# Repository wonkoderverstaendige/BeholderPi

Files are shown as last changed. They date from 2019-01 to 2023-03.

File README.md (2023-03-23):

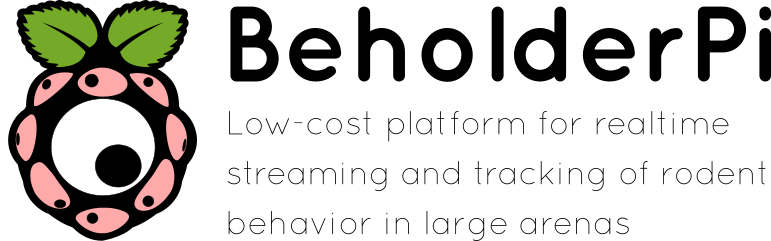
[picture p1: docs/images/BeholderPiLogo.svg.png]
BeholderPi logo BeholderPI logo


# Outline

- scalable array of networked camera nodes
- low-cost (relatively) ~100--200 Euro/node
- 800x600 @ 30 fps in visible or IR
- low latency preview of merged views
- synchronized to sub-millisecond time resolution
- hardware accelerated encoding
- synchronization with external systems (e.g. elecrophysiology recordings)

# Hardware

- [RaspberryPi 3B+/4B](https://www.raspberrypi.org/documentation/hardware/raspberrypi/README.md)
- [Raspberry/Picamera compatible camera module](https://www.raspberrypi.org/documentation/hardware/camera/README.md)
    - e.g. Camera Module v2 (8MP, FOV: 62.2° horizontal, 48.8° vertical)
    - **Read:** [How the PiCamera works](https://picamera.readthedocs.io/en/release-1.13/fov.html)
- [PoE hat](https://www.raspberrypi.org/products/poe-hat/) for power/network
- A decent receiving computer (ideally 1 CPU core/node)
- optional hardware encoding GPU
- PoE capable ethernet switch if PoE is used

# Software
- based on Picamera, ZMQ, OpenCV, FFmpeg

# Inspiration
## Raspicam paper
Inspiration of the system was taken from prior work done by [Saxena et al. 2018](https://www.physiology.org/doi/full/10.1152/jn.00215.2018),
[code here](https://github.com/DeshmukhLab/PicameraPaper).

# Installation
1) [System Overview](docs/SystemOverview.md)
2) [Beholder Installation](docs/Installation_Beholder.md)
3) [Eye Installation](docs/Installation_Eye.md)
4) [General Usage](docs/Usage.md)
5) [Troubleshooting](docs/Troubleshooting.md)

## Hardware
- [Camera Mounts](docs/CameraMounts.md)
- [Sync Lights](docs/SyncLights.md)

## Processing
- [Stitching](docs/processing/Stitching.md)
- [Synchronization](docs/Synchronization.md)
- [Tracing](docs/Tracing.md)
- [Tracking](docs/Tracking.md)

# TODO
- see [current todo list](docs/todo.md)

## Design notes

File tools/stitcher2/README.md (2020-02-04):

# Stitching Videos
Create a new directory named with the timestamp of the videos and copy the original copies into it.

## Calculate alignment matrix
For each camera angle we need to pre-calculate the transformation matrix with the GUI tool. Start the GUI with
    
    `python align_gui.py --target [target image path] [source image path]`

where the target image is a ground-truth image of a flat top-down view on the maze
For example:

    `python align_gui.py --target "D:\data\targets\mouse_hexmaze.png" "D:\data\2018-10-02_04-40-59_cam_0.avi"`
    
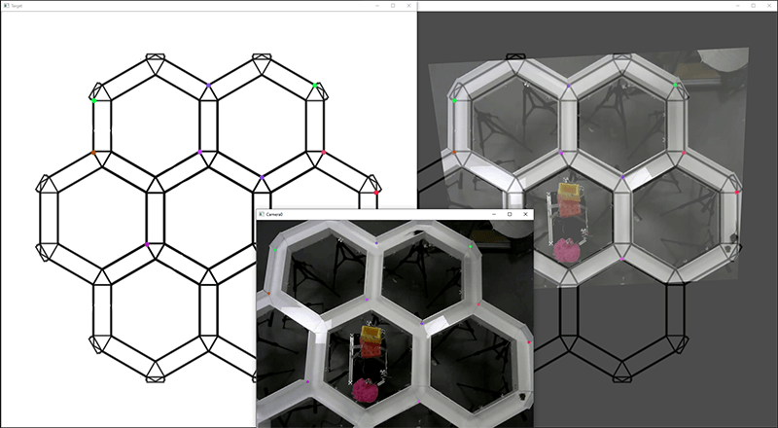
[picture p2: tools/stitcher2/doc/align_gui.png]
Align GUI

   
The GUI should open three windows. One is the target image, one the source camera view, and one a preview. Double click
on a point in the target view, a colored dot appears marking the location. Double click on the corresponding location
in the source view. A dot with the same color should appear there, too. The dots should all represent locations in a
single plane, for example the floor of the maze. This is important!

Once three such points where added, the preview should update and show you the current estimate, but will only align
well when at least four point pairs were added. When you are happy with the alignment, press `s` on the keyboard to
save, and `q` to quit. The transformation (homography) matrix, label and preview images are stored alongside the 
original files. Check they are ok.

Repeat for all cameras/videos.

## Stitch images
With the precalculted transformation matrix the images can now be perspective corrected and merged.

`python stitch.py --target [target path] [sources]`

Sources should be paths all camera views. To make it easier, if they all have the same name and just different camera 
number as is usually the case, the source can be specified with a wildcard, either `?` or  `*`. For example:

`python stitch.py --target "targets\mouse_hexmaze.png" "D:\data\2018-10-02_04-40-59_cam_*.avi"`

Additional parameters of note are `--preview`, giving you a preview of what happens. This is great to tune in on a final
look, but slows processing down. `--cropx` and `--cropy` allow to trim the borders of the image. `--delays` allows to 
either start the video in the middle instead of the start, but also to compensate for temporal lag between the cameras.
If `--skip` is used it must be specified for each source. E.g. for a two camera set of videos `--skip 0 0`.
Together with `--num_frames` to limit the number of frames to be extracted, segments in the middle of a session can be
extracted.

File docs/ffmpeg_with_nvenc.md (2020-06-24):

```sh
sudo add-apt-repository ppa:graphics-drivers/ppa
sudo apt-get update && sudo apt-get -y upgrade
sudo apt-get install nvidia-kernel-source-418 nvidia-driver-418
```

This will cause freezes of the ubuntu desktop due to a conflict between the nvidia
drivers and the HWE stack. We need to reinstall the non-HWE Xorg packages.

`sudo apt install ubuntu-desktop` should pull all the non-Xorg packages in.

Next we need to grab the nvidia headers:

```sh
git clone https://git.videolan.org/git/ffmpeg/nv-codec-headers.git
cd nv-codec-headers
make
sudo make install
```

## The snap way (BAD)
Then we can just install the latest ffmpeg snap (e.g. 4.1 seems to work) with
`-nvenc-enabled` flag.

`sudo snap install ffmpeg`

--> HOWEVER, the snap has atrocious startup times, many times longer, especially the first launch. This can cause issues with dropped frames.

## The non-snap way (GOOD)
Instead we want to compile our own ffmpeg with NVENC support. Luckily I did this without taking notes due to time pressure in the moment... so you are on your own.

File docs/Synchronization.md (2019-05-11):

# NTP synchronization
## Chrony
Chrony acts as both NTP client as well as NTP server. We want to quickly synchronize on startup and then keep all
devices closely locked to within ~1 ms.

- Beholder acts as NTP server (with the `allow` directive).
- Spectator as secondary server to keep all log files and events synchronized?

## Current state (11-May-2019)
- chrony on Beholder keeps halting. Perhaps networking issue to sources on startup?

## Logging
- track logging information on the eyes to see actual offsets and throw into influxdb?

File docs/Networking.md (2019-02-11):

# Setup

When setting up, we need access to the internet (to pull packages etc.).
After that we can switch to the local beholder.pi network.

When connecting a freshly flashed raspberry, it will start broadcasting
discovery packages.

The `spectator` raspberry is running the local DHCP and DNS servers on
10.0.0.1 and has a static IP reserved for the beholder (currently antigoon)
at 10.0.0.11.

 >TODO: Install NTP server, too.

# Bootstrapping

- monitor the appearance of a new host in the discovery table.
- look up MAC adress of the new host:
    `ssh pi@host.ip 'cat /sys/class/net/eth0/address'`
- enter new MAC mapping in the `ansible/setup/network/vars.yml` file
- enter temporary IP in `ansible/setup/network/inventory`
- Execute the network setup playbook in the `ansible/setup/network` directory:
    `ansbible-playbook -i inventory main.yml`

This should set up the new host with proper IP.

- Verify new IP and correct host name in the discovery table
- update eye IP in `ansible/setup/network/inventory` file

> TODO: allow passing a new_host_ip variable to target only new hosts

<!--# Maintenance-->

<!--- For each node, start up wifi, connect to access point-->
<!--- update-->
<!--- shut down wifi-->

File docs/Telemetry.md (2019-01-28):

# InfluxDB telemetry

- install Raspbian Stretch Lite
- update && upgrade, set up ssh, keyboard, passwd, vim, byobu, htop etc...
- Set up InfluxDB repo
	- `$ curl -sL https://repos.influxdata.com/influxdb.key | sudo apt-key add -`
	- `$ echo "deb https://repos.influxdata.com/debian stretch stable" | sudo tee /etc/apt/sources.list.d/influxdb.list`
	- `$ sudo apt update`
	- `$ sudo apt install telegraf`, install also `influxdb kapacitor` on main pi

## InfluxDB
- `$ sudo systemctl start influxdb`, defaults to port 8086
- `$ influx` to start influxdb shell, `> auth` to authenticate

Influxdb will require authentication the moment here is a admin user.

- `> CREATE USER admin WITH PASSWORD 'adminpw' WITH ALL PRIVILEGES`
- in `/etc/influxdb/influxdb.conf` under `[http]` set `auth-enabled = true`

- `> CREATE DATABASE telegraf`
	- `> SHOW DATABASES`
    - `> CREATE USER telegraf WITH PASSWORD 'userpw'`
    	- (`> SET PASSWORD FOR "user" = 'abcdef'`  to change)
    - `> GRANT ALL ON telegraf TO telegraf`
    - `> SHOW USERS`
    
    Optionally set the retention policy to reduce space use
    - `> CREATE RETENTION POLICY thirty_days ON telegraf DURATION 30d REPLICATION 1 DEFAULT`
    - `> SHOW RETENTION POLICIES ON telegraf`

## Telegraf

To store the configuration file in the github repo, we need to either
modify the telegraf service, or link the default location to our version.

- create symlink from `/etc/telegraf/telegraf.conf` to repo conf file
- Add password and username environment variables to `/etc/default/telegraf`
- Add telegraf user to video group: `sudo usermod -G video telegraf` to access the videocore temperature sensor
- `$ sudo systemctl start telegraf`

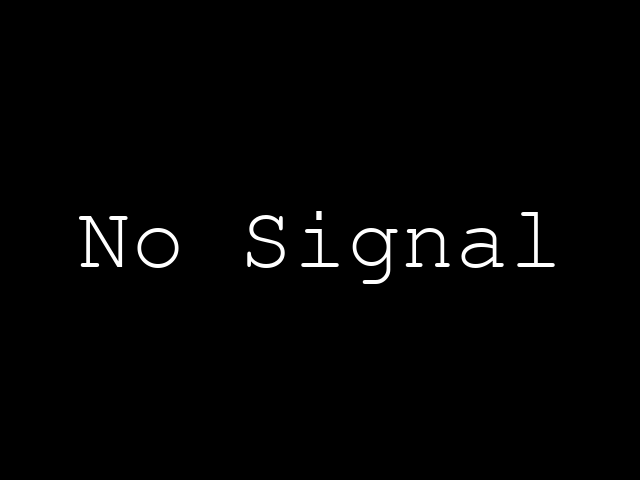
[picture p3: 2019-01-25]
beholder/resources/no_signal.png

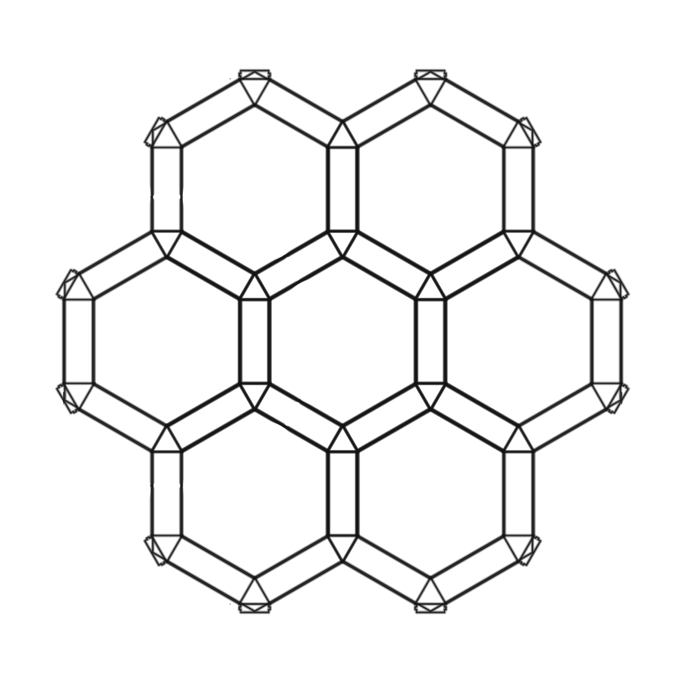
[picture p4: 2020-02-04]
tools/stitcher2/targets/mouse_hexmaze_1200p.png

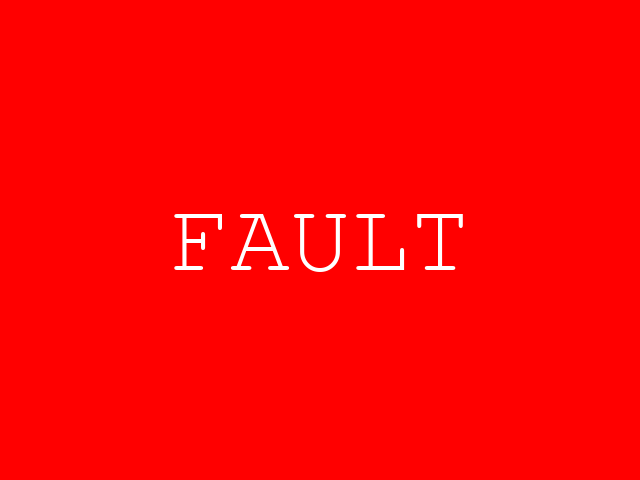
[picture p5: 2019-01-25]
beholder/resources/fault.png

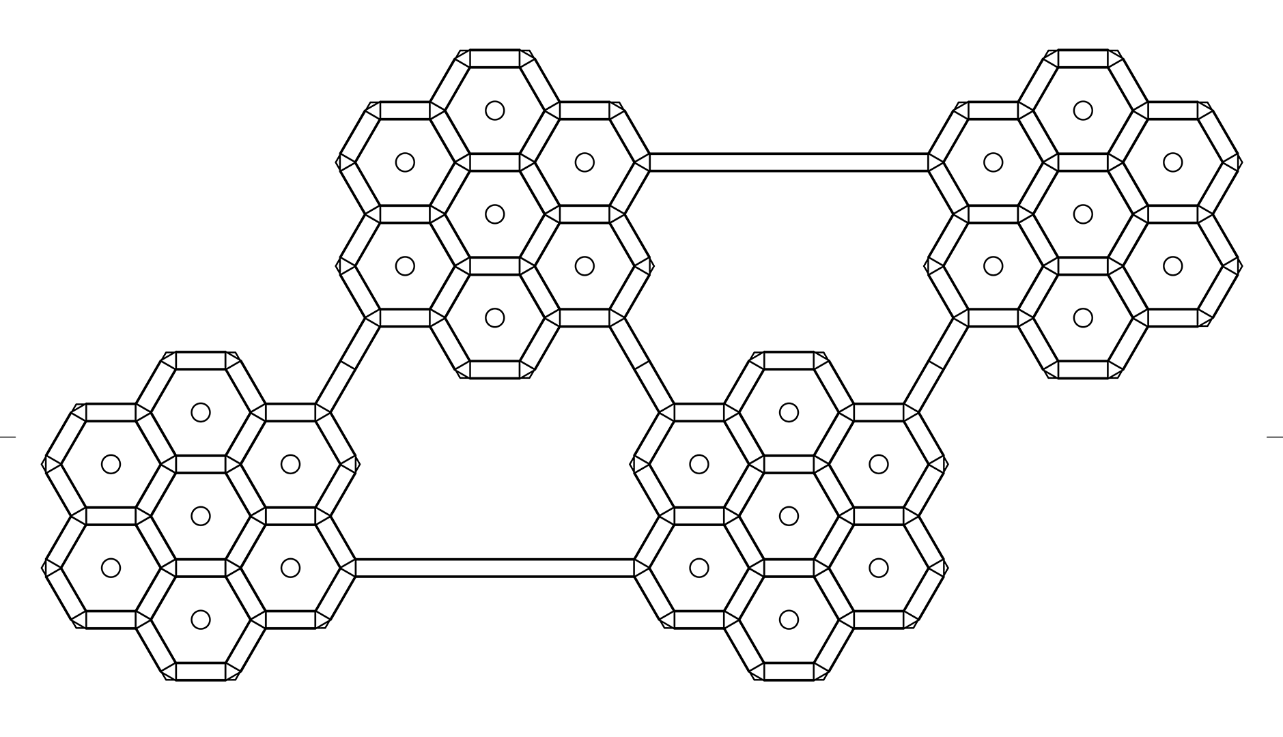
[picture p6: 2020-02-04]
tools/stitcher2/targets/rat_hexmaze1080p.png

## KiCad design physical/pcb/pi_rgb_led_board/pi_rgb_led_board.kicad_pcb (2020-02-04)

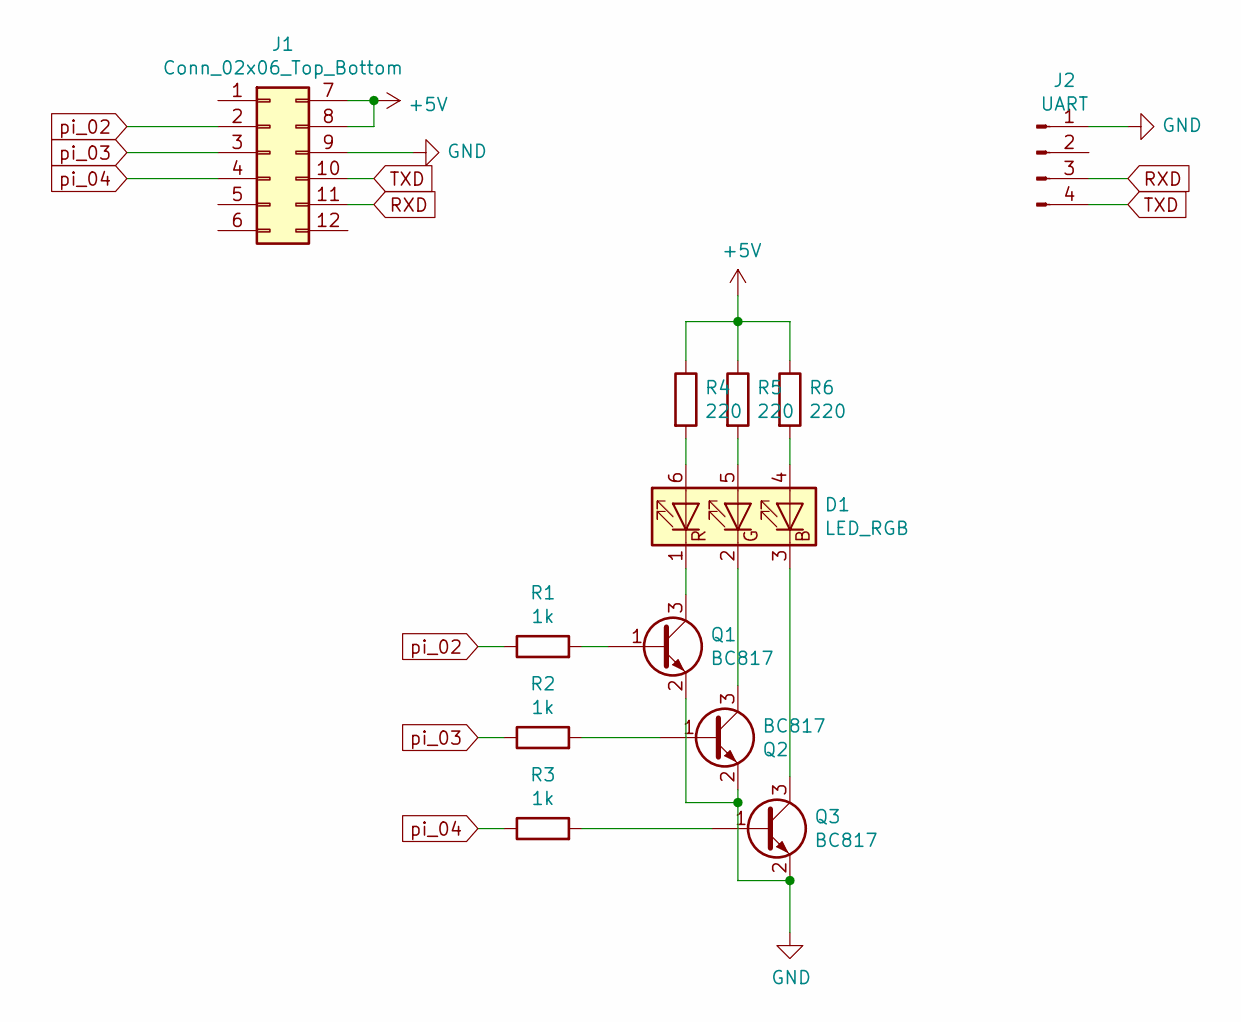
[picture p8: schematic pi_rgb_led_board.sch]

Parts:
D1: LED_RGB; LED_RGB_5050-6
J1: Conn_02x06_Top_Bottom; PinHeader_2x06_P1.27mm_Vertical
J2: UART; PinHeader_1x04_P1.27mm_Vertical
Q1, Q2, Q3: BC817; SOT-23
R1, R2, R3: 1k; R_0805_2012Metric
R4, R5, R6: 220; R_0805_2012Metric

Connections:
+5V: J1.7, J1.8, R4.1, R5.1, R6.1
GND: J1.9, J2.1, Q1.2 (E), Q2.2 (E), Q3.2 (E)
unnamed: D1.1 (RK), Q1.3 (C)
unnamed: D1.2 (GK), Q2.3 (C)
unnamed: D1.3 (BK), Q3.3 (C)
unnamed: D1.4 (BA), R6.2
unnamed: D1.5 (GA), R5.2
unnamed: D1.6 (RA), R4.2
unnamed: Q1.1 (B), R1.2
unnamed: Q2.1 (B), R2.2
unnamed: Q3.1 (B), R3.2
RXD: J1.11, J2.3
TXD: J1.10, J2.4
pi_02: J1.2, R1.1
pi_03: J1.3, R2.1
pi_04: J1.4, R3.1

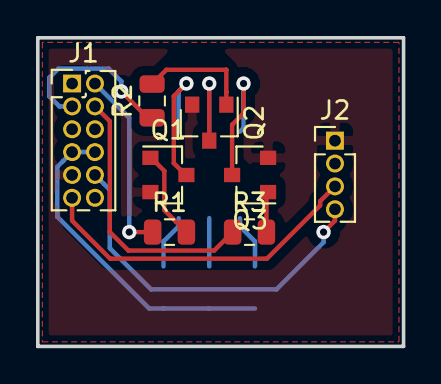
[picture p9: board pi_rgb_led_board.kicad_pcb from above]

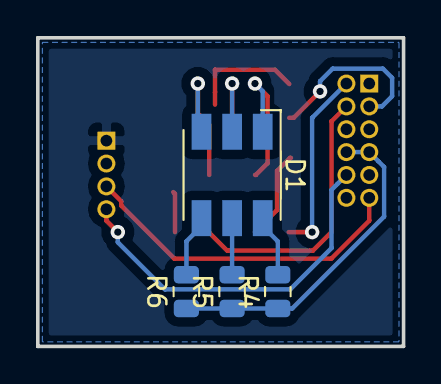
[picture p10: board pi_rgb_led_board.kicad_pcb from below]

Board: 2 copper layers, 20.3 x 17.1 mm, 12 parts (4 on the bottom side), 16 nets.

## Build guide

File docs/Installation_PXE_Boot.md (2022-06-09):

# Clients
## Pi 3
raise NotImplementedError

## Pi 4
Check current bootloader configuration (see [Pi4 Boot EEPROM docs](https://www.raspberrypi.com/documentation/computers/raspberry-pi.html#raspberry-pi-4-boot-eeprom)):

`sudo vcgencmd bootloader_config`

we want FREEZE_VERSION=1 and BOOT_ORDER=0x421 (L->R USB, NET, SD).

`sudo apt install rpi-eeprom`

`sudo -E rpi-eeprom-config --edit` to edit directly or

`sudo rpi-eeprom-config --apply pxe_boot.conf` to use a file

Finalize update with reboot.

# Server
## Mount points
`sudo mkdir -p /tftpboot`

`sudo chmod 777 /tftpboot`

The individual clients get their `/boot` from subdirectories in `/tftpboot`, either by MAC or IP as
configured in `dnsmasq.conf` under `tftp-unique-root`, e.g. `/tftpboot/10.0.0.103` containing the kernel, config
and `cmdline.txt` pointing to the NFS image.

One NFS mount point per client/eye

`sudo mkdir -p /nfs/eyeXX` 

for ease of access, we'll make the content in home and then move+chown to `root:root`

Copy either from a setup eye:

`sudo rsync -e "ssh -i /home/pi/.ssh/id_beholderpi" -xa --progress / pi@10.0.0.1:eye_base`

or copy from own root:

`sudo rsync -xa --progress --exclude /nfs --exclude /etc/systemd/network --exclude /etc/dnsmasq.conf  / /nfs/eye_base`

Permissions are important - `/usr/bin/sudo` must be owned by root and `chmod 4577` to work, home should be owned by `pi`

## Individual NFS roots
For each client create a NFS mount via copy from base image

`sudo rsync -xa /nfs/eye_base /nfs/eyeXX`

### Chrooting
`cd /nfs/eyeXX
sudo mount --bind /dev dev
sudo mount --bind /sys sys
sudo mount --bind /proc proc
sudo chroot . rm /etc/ssh/ssh_host_*
sudo chroot . dpkg-reconfigure openssh-server
sudo chroot . systemctl enable ssh
sudo umount dev sys proc`

## Disable dhcpcd
`sudo systemctl stop dhcpcd
sudo systemctl disable dhcpcd`

## dnsmasq config
On top of default dnsmasq config for spectator
`interface=eth0
no-hosts
enable-tftp
tftp-root=/tftpboot
pxe-service=0,"Raspberry Pi Boot"`

## tftp service
Copy the `/boot` off a configured eye (i.e. ssh, camera etc. enabled).

`sudo cp -r /boot/* /tftpboot`

or

`sudo rsync -e "ssh -i /home/pi/.ssh/id_beholderpi" -xa --progress /boot pi@10.0.0.1:`

and then some manual moving + chowning to `root:root`.

Edit kernel parameters in `/tftpboot/cmdline.txt`:

```console=serial0,115200 console=tty1 root=/dev/nfs 
nfsroot=10.0.0.1:/nfs/eye03,vers=3 rw ip=dhcp rootwait elevator=deadline```

## NFS
Add exports in `/etc/exports`:

```
/nfs/eyeXX *(rw,sync,no_subtree_check,no_root_squash)
/tftpboot *(rw,sync,no_subtree_check,no_root_squash)
```

edit `/nfs/eyeXX/etc/fstab`:

`proc       /proc        proc     defaults    0    0
10.0.0.1:/tftpboot /boot nfs defaults,vers=3 0 0`

# Enable services

`sudo systemctl enable rpcbind
sudo systemctl restart rpcbind
sudo systemctl enable nfs-kernel-server
sudo systemctl restart nfs-kernel-server`

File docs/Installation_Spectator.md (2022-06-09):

# Base OS
Prepare and flash the ansible-ready OS image (last tested with Raspberry OS Buster 04.2022) generated with the image
preparation script.

# Network

`ansible-playbook ansible/install_spectator.yml --private-key ~/.ssh/id_beholderpi --inventory ansible/inventory-local`

# OFFLINE/ INSTALLATION
NOTE: In the CDL, there's not internet for the Pi's as LAN is blocked and Wifi requires access via a captive portal.
This means we can't run ansible to install the packages required.

Network via USB tether, then manually run all the steps ansible would do for us!
- apt install all packages listed in the playbook
- pip3 install pyyaml (why again?)
- copy and rename the up network devices templates into `/etc/systemd/network/`
- disable dhcpcd `systemctl disable dhcpcd` and enable networkd and dnsmasq
- rename in `/etc/hostname` and `/etc/hosts`
- overwrite chrony and dnsmasq configs from templates to `/etc/dnsmasq.conf` and `/etc/chrony/chrony.conf`
- modify `dnsmasq.conf` with the required MAC adresses

## OPTIONAL - DEV
Set up wifi to use as bridge into the 10.0.0.* subnet to have access without direct wiring into it.

Configure the spectator to use static IP.

`sudo apt install rsync dnsmasq chrony tcpdump`

Create `10-eth0.netdev` and `11-eth0.network` files in `/etc/systemd/network/`

- dhcpcd still default enabled on Buster, needs to be disabled.

Get client MAC and Serial

MAC: `ethtool -P eth0 | cut -d ' ' -f 3`
Serial: `grep Serial /proc/cpuinfo | cut -d ' ' -f 2 | cut -c 8-16`

# Notes on WIFI
Using Wifi on the spectator allows to have it both a connection to the eye network and the surrounding LAN/internet,
but requires routing setup to not interfere with each other.

Using the `wpa_supplicant-wlan0.conf` from `ansible/templates/spectator` in `/etc/wpa_supplicant/`:

`sudo systemctl enable wpa_supplicant@wlan0
sudo systemctl start wpa_supplicant@wlan0`

Checking for configured status via `sudo networkctl status wlan0`.

The network config files in `ansible/templates/spectator` have Metric hints, check with `route -n` that 
`eth0` has higher metric than `wlan0`. The routing table could be configured more fine-grained to use `eth0`
only for traffic in the `10.0.0.*` direction.

# PXE/Network Boot
see `Installation_PXE_Boot.md`

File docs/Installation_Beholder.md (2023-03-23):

# Hardware
- decently powered desktop GPU
  - a core per stream is recommended
- optionally a hardware encoding capable GPU
  - even smaller NVIDIA Quadro cards allow multiple encode/decode streams
  - note consumer cards are limited to 2 streams only and hence useless for larger setups
- ideally two network interfaces
  - it's best to keep the eyes on their own isolated subnet

# OS and Environment
- default Ubuntu 22.04 LTS
- Install AnyDesk (optional, only for our setup)
- `apt install build-essential vim git htop byobu unzip wget cmake yasm`
- copy `id_beholderpi` ssh keys

# The whole NVIDIA mess...
It can be tricky to match compatible versions of the nvidia-drivers, nvidia-compute-utils, nvidia-cuda-toolkit and the
ffmpeg nv headers. Best use the nvidia repositories to get cuda, which comes with
a matching driver etc., then we just need to make sure the ffmpeg nv headers
are up to date to work with them.

See https://docs.nvidia.com/cuda/cuda-installation-guide-linux/index.html#ubuntu
- `wget https://developer.download.nvidia.com/compute/cuda/repos/ubuntu2204/x86_64/cuda-keyring_1.0-1_all.deb`
- `sudo dpkg -i cuda-keyring_1.0-1_all.deb`
- `echo "deb [signed-by=/usr/share/keyrings/cuda-archive-keyring.gpg] https://developer.download.nvidia.com/compute/cuda/repos/ubuntu2204/x86_64/ /" | sudo tee /etc/apt/sources.list.d/cuda-ubuntu2204-x86_64.list`

Pin file to prioritize CUDA repo, then install CUDA:
- `wget https://developer.download.nvidia.com/compute/cuda/repos/ubuntu2204/x86_64/cuda-ubuntu2204.pin`
- `sudo mv cuda-ubuntu2204.pin /etc/apt/preferences.d/cuda-repository-pin-600`
- `sudo apt update && sudo apt install cuda`
- Reboot
- Add CUDA to PATH in `.bashrc`, else `nvcc` won't be found
  - `PATH="/usr/local/cuda/bin:$PATH"`

## FFMPEG with Nvidia nvenc
### Install Headers
- `git clone https://github.com/FFmpeg/nv-codec-headers.git`
- `cd nv-codec-headers && sudo make install && cd –`

### FFMPEG from source
- `apt install build-essential yasm cmake libtool libc6 libc6-dev libnuma1 libnuma-dev`
- `git clone https://git.ffmpeg.org/ffmpeg.git ffmpeg/`
- `cd ffmpeg`

**Note: Perhaps static is better to not be affected if libs change/wander about with driver updates?**
- `./configure  --enable-nonfree --enable-cuda-nvcc --enable-libnpp --extra-cflags=-I/usr/local/cuda/include --extra-ldflags=-L/usr/local/cuda/lib64`

- **Else we can compile with shared libs:**
- `./configure --enable-nonfree --enable-cuda-nvcc --enable-libnpp --extra-cflags=-I/usr/local/cuda/include --extra-ldflags=-L/usr/local/cuda/lib64 --disable-static --enable-shared`

- add ffmpeg/ffprobe to PATH, either copy executables to `~/.local/bin` or make local bin directory with links:
  - `mkdir ~/bin && cd bin`
  - `ln -s ~/src/ffmpeg/ffmpeg ffmpeg_gpu`
  - `ln -s ~/src/ffmpeg/ffprobe ffprobe_gpu`
  - Append to `~/.bashrc`:
  ```bash
  if [ -d "$HOME/bin" ] ; then
    PATH="$HOME/bin:$PATH"
  fi
  ```

# Beholder
## Python
- download Anaconda or miniconda Python from https://anaconda.com
- `chmod +x <installer-file-name>.sh`
- `./<installer-file-name>.sh`
- Accept licence and use default `$HOME/anaconda3` path
- init anaconda (in installer, or via `conda init`)
- restart shell, conda base should be active `(base) username@beholder-desktop:~$ `
- update conda `conda update -n base -c defaults conda`

## BeholderPi
Clone the repo
- `cd ~/src/`
- `git clone https://github.com/wonkoderverstaendige/BeholderPi`
- `cd BeholderPi`

Resolving the `requirements.yaml` file will take several minutes!
- `conda env create -n beholder -f requirements.yaml`
- `conda activate beholder`

Install the actual beholder package and make launcher scripts accessible
- `pip install -e .`
- `cp scripts/launchers/* ~/bin/`

check if beholder launches with `beholder`

# NTP/Chrony
- `sudo apt install chrony`
- Disable systemd NTP service 
  - `sudo timedatectl set-ntp off`
- copy the chrony conf file
  - `mv /etc/chrony/chrony.conf /etc/chrony/chrony.conf.bak` 
  - `cp ~/src/BeholderPi/ansible/templates/beholder/chrony.conf.j2 /etc/chrony/chrony.conf`
- `sudo systemctl enable --now chrony`

## Verify NTP synchronization
- check `chronyc tracking` on beholder
  - connected to a reference server?
- check `chronyc tracking` on spectator+eyes
  - is beholder PC the reference server and are offsets low? 

# Disable automatic upgrades of especially the nvidia drivers etc.
- `sudo apt-mark hold `:
  - `nvidia-compute-utils-XXX`
  - `nvidia-dmks-XXX`
  - `nvidia-driver-XXX`
  - `nvidia-kernel-common-XXX`
  - `nvidia-kernel-source-XXX`
  - `nvidia-utils-XXX`
  - `nvidia-modprobe`
can be reversed with `apt-mark unhold ...`

# Conveniences
- disable screen suspend
- disable sleep/hibernate/power keys to prevent accidental shutoffs mid experiment
  - `sudo -e logind.config`
  - uncomment and change `HandleSuspendKey` and  `HandleHibernateKey` to `ignore`

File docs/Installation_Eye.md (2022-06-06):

# SD card installation
To bootstrap network discovery and [Ansible](https://www.ansible.com/) access, the default RaspbianOS
image is modified with the bash script in `scripts/prepare_raspbian_eyestalk_image.bash`.
It copies files required for the initial services, enables ssh, copies ssh keys and sets default passwords.

Running the script will require `sudo`, as does flashing to SD card. When flashing with the official flasher,
make sure not to modify any of the configuration there as it may override changes made by us. 

# Discovery of Pi

# Ansible setup
From a linux machine with ansible installed, run the following from outside the `BeholderPi/ansible` directory
(ansible does not like running from the working directory containing the playbook).

`ansible-playbook ansible/install_eye.yml 
    --private-key ~/.ssh/id_beholderpi
    --inventory ansible/inventory-local
    --extra-vars "@ansible/vars_eyes-local.yml"
    --limit new_eyes`

# What the Script does
RaspberryIS Buster is distributed with SSH is disabled by default.
To enable, an (empty) `ssh` file needs to be present in the `/boot` partition

See this [blog post](https://kenfallon.com/safely-enabling-ssh-in-the-default-raspbian-image/)
for details.

Add beholderpi key to the known_known hosts of all devices, including
*spectator* and *beholder*

### Network
The *spectator* RaspberryPi acts as DNS and DCHP server for all hosts on the
10.0.0.* network. It serves with the `dnsmasq` package.

> TODO: Make a template of the *spectator* `dhcpcd.conf` and `dnsmasq.conf`.

- `apt install dnsmasq`

### Security
- copy ssh keys
- prevent/allow password authentication

### Network discovery

To facilitate host discovery by the master *beholder* instance
in an unknown network environment (external DHCP? static IPs?),
the nodes run a systemd service broadcasting __UDP on port 50101__ with
messages containing IP and hostname (`IP:hostname`, though IP is strictly
not needed and known from the socket connection).

The system running Ansible can then take over given
a list of ssh-enabled hosts and apply their roles (including adjusting
the hostnames).

#### Discovery Sender setup
This requires copying the `beholder_discovery_sender.py` files to the
home directory of the `pi` user, the `beholder_discovery_sender.service`
to `/etc/systemd/system` as well as enabling the systemd unit file to
launch on reboot by creating a symlink to it in
`/etc/systemd/multi-user.target.wants`. Upon reboot the script will
continuously broadcast at ~ 3s intervals.

The machine running Ansible now only has to listen on UDP port 50101
to discover client addresses to include as hosts.

#### Discovery Receiver setup

Just launch the `scripts/services/discovery/beholder_discovery_reciever.py`
script.

# Ansible Playbooks

The following tasks are required:

## Eyes

### Network configuration
- set up hostname and configuration (e.g. network)
> Launch the ansible/setup/network playbook

__For more detail see (Networking.md)[Networking.md]__

### Basic packages
- install packages (python3, ntp, camera, git, vim, htop, byobu)

### Telemetry
- install and configure telemetry (telegraf)

### BeholderPi code
- clone and install BeholderPi repository
- install service for camera feed
- update any service affected by new code (discovery, streaming)

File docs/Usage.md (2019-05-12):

# How to use this code

# Install on BeholderPC

# Install on raspberries

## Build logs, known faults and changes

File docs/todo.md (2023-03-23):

[ ] chrony beholder
[ ] complete Readme revamp
    - hardware overview
    - Beholder Installation
    - eye installation
    - software walkthrough
    - troubleshooting
    - synchronization

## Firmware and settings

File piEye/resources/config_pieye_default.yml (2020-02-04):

# Camera configuration
camera_sensor_mode: 4
camera_rotation: 90
camera_framerate: 30.
camera_exposure_mode: 'sports'
camera_brightness: 38
camera_awb_mode: 'off'
camera_awb_gains: [[159, 128], [599, 256]]

# Image flip
# the bottom row of images has to flip to pu the timestamp field outside of the maze
camera_vflip: ['eye07', 'eye08', 'eye09', 'eye10', 'eye11', 'eye12']
camera_hflip: ['eye07', 'eye08', 'eye09', 'eye10', 'eye11', 'eye12']

# Frame resize. Note that frame dimensions must take rotation into account
frame_width: 600
frame_height: 800

# Preview
camera_preview_enable: false
camera_preview_alpha: 200
camera_annotate_metadata: true
camera_annotate_frame_num: true
camera_annotate_text_size: 16
camera_annotate_bg_color: 'black'

# Capture
camera_recording_format: 'mjpeg'
camera_recording_bitrate: 25000000

# Connection
zmq_output_port: 5555
zmq_topic_video: piEye

# Debug options
debug_drop_nth_frame: false
camera_stream_duplication: 1

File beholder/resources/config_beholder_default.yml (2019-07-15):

# Shape of the camera feeds
frame_width: 600
frame_height: 800
frame_colors: 3
frame_fps: 30.

# Display arrangement
n_rows: 2

# ZMQ frame sources
sources: ['10.0.0.101:5555',
          '10.0.0.102:5555',
          '10.0.0.103:5555',
          '10.0.0.104:5555',
          '10.0.0.105:5555',
          '10.0.0.106:5555',
          '10.0.0.107:5555',
          '10.0.0.108:5555',
          '10.0.0.109:5555',
          '10.0.0.110:5555',
          '10.0.0.111:5555',
          '10.0.0.112:5555',
          ]

frame_crop_x: 104
frame_crop_y: 91

scale_floor: 4.28  # mm/px
scale_arena: 3.30  # mm/px

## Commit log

2019-01-28 debug option to drop n-th frames
2019-01-28 Debug message on intentional frame drops
2019-01-28 Shuffle frame drops
2019-01-28 More information on frame skip event
2019-01-28 Rename Grabber and Writer threads, lower intentional frame drop rate
2019-01-28 Dropped frame message wording
2019-01-29 Bump framerate to 30 fps
2019-01-29 Fix frame source restart warning
2019-02-05 Bump framerate to 30.0 fps on Beholder
2019-02-05 Differentiate probable intentional frame drop and unexpected frame drop
2019-02-06 Switch announcing service to UDP broadcast
2019-02-10 Disable printing packet details
2019-02-11 Show hostname in frame annotation
2019-02-11 Fix camera stream duplicatio config uptake by eye streamer
2019-02-12 Fix flipped frame shape for 800x600 test
    [config_pieye_default.yml]
2019-02-12 Match instance and file names to 1-indexed device IDs
2019-02-12 Increase heartbeat rate to 1Hz
2019-02-12 Tighten discovery state tolerances
2019-02-17 Resize fault/disconnect frames to match configuration
2019-02-17 Re-enable frame annotations
2019-05-06 Bump grabber frame queue size from half a second to around 5 seconds
2019-05-06 Ignore dead threads on shutdown
2019-05-06 Simplify display frame buffer. GIL takes care of shared array access.
2019-05-08 Conditionally flip frames
2019-05-08 Crude distance measure for calibration
2019-05-08 Fancier crude distance measure for calibration
2019-05-08 Even fancier crude distance measure for calibration
2019-05-09 Add center calibration cross-hair
2019-05-09 Stop center calibration cross-hair from blinking
2019-05-11 Host specific frame flip option
    [config_pieye_default.yml]
2019-05-11 eye flip list fix
    [config_pieye_default.yml]
2019-05-11 Disable intentional frame drop as productive use nears
2019-05-11 Frame flip for bottom row to move metadata out of ROI
2019-05-12 Factor out frame annotation
2019-05-13 Remove an annoying print
2019-05-14 Refine calibration tool
2019-05-28 Testing new eye debug print
2019-05-28 callback frame number in image
2019-06-01 Initial Tracer tool for manual tracking
2019-06-01 Optional device-local beholder config and config file CLI parameter
2019-06-02 Update tracer with more accurate node distance calculations
2019-06-02 MazeGraph prototype expansion
2019-06-03 Add recording button debounce time to prevent trigger spam
2019-06-03 Move rec button debounce logic around to account for trial-trigger start
2019-07-16 Adjust button code to trigger trial by Logitech presenter
2019-07-16 Minor fixes to tracer tool
2019-07-23 command message exchange prototype
2019-07-23 command message exchange prototype pt. 2
2019-07-23 Print camera metadata for testing
2019-07-25 Store frame sizes
2019-07-25 Tracer log file format dataset name prefix
2019-07-25 Allow deprecated single- and current multipart transfers from zmq
2019-07-25 Disable unused command input socket
2019-07-25 Fixed brightness and white balance defaults
    [config_pieye_default.yml]
2019-07-25 fix typo in config. Argh.
    [config_pieye_default.yml]
2019-07-27 Reduce tracer UI wait time
2019-10-14 Initial repair script to stitch with missing camera views
2020-02-01 Dummy Server prototype
2020-02-01 Fix non-square frame creation
2020-02-02 Allow flipped camera views for stitch-align
2020-02-02 Allow skipping frames to compensate frame rate differences
2020-02-04 RGB board prototype
    [pi_rgb_led_board.kicad_pcb, pi_rgb_led_board.sch]
2020-02-13 Include frame naming offset parameter
2022-04-13 eye image generation updated to raspberrypi OS with custom user
2022-06-09 Fix zero-indexed camera labels in videos
2023-03-23 Truncation resistant recording startup
